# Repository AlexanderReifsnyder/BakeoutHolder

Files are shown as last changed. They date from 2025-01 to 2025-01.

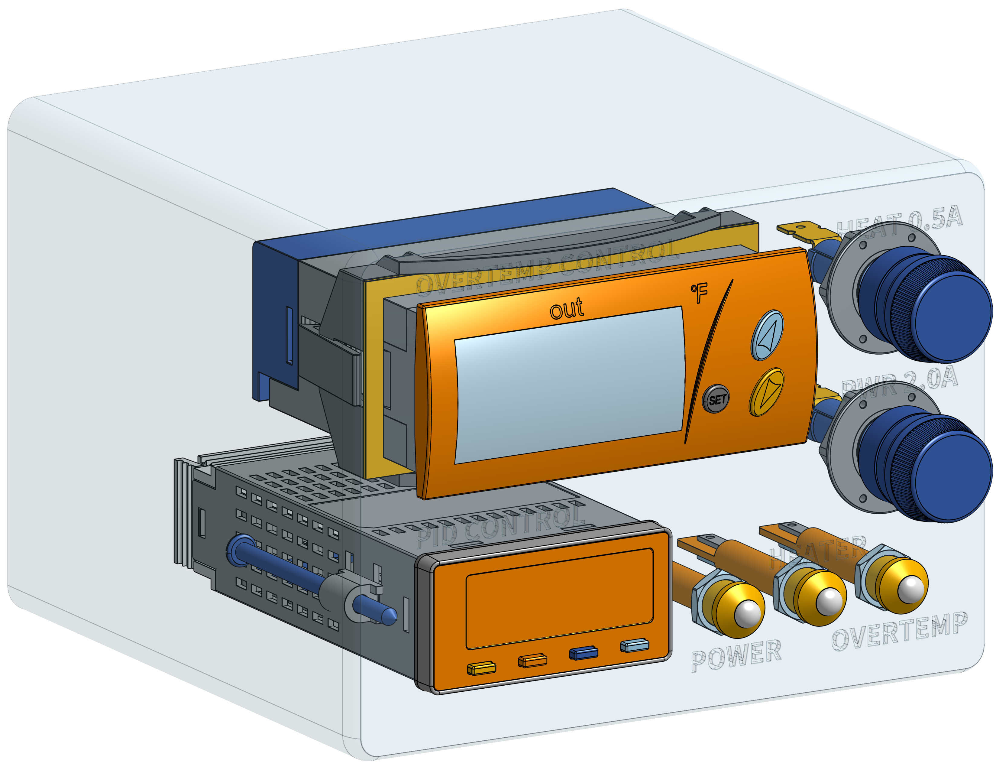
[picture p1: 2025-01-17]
Prototype/Version 1/Electronics/Controller Assembly Transparent V1.png

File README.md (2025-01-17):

# BakeoutHolder
The goal of this project was to create a heated holder for baking samples in a dry pumping station. The design is currenty in the prototype stage and should not be considered an official release. You may encounter incomplete features or unexpected behaviors - proceed at your own discretion. Th repository currently has STEP files for all physical components broken into folders depending on manufacturing method, and a BOM with links to the products used in our prototype.
This project has been released under the [Creative Commons Attribution-NonCommercial-ShareAlike 4.0 International license](https://creativecommons.org/licenses/by-nc-sa/4.0/?ref=chooser-v1).

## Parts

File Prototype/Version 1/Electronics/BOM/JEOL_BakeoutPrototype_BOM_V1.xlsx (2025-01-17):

Description | Qty | Units | Part Number | Supplier | Price/Unit | Subtotal
Insertion Heater with Standard Wire Lead Covering for 3/16" Hole, 120V AC, 1-1/2" Long Heating Element, 20W | 1 | Each | 3618K511 | McMaster Carr | $38.71 | $38.71
Thermocouple Probe for Air and Surfaces Type T, Wire Leads, 3 Feet Cable Length | 2 | Each | 9251T71 | McMaster Carr | $23.54 | $47.08
Electrical-Insulating Tube Sleeving with Acrylic Coating, 1/2" ID, 3 Feet Long | 1 | Each | 8268K72 | McMaster Carr | $11.66 | $11.66
Power Cord Light Duty, NEMA 5-15 Plug, 6 Feet Long, 0.31" Wide, SPT-1 | 1 | Each | 70355K85 | McMaster Carr | $4.14 | $4.14
Autotuning Temperature Controller with 1 Mechanical Relay Output, 1/32 DIN | 1 | Each | 38615K171 | McMaster Carr | $169.90 | $169.90
Super-Resilient Kalrez 7075 O-Ring Ultra-Chemical-Resistant, 1/16 Fractional Width, Dash 015 | 1 | Each | 1280N24 | McMaster Carr | $69.92 | $69.92
Panel-Mount Holder for Glass and Ceramic Tube Fuse for 1/10-16A Fuse, 0.25" Wide Straight Quick-Disconnect Terminal | 3 | Each | 7087K43 | McMaster Carr | $8.62 | $25.86
Glass-Tube Fuses Fast-Acting, Manufacturer Equiv: 217, GDB and Gsb, 2A | 1 | Pack of 5 each | 6978K769 | McMaster Carr | $6.71 | $6.71
Glass-Tube Fuses Fast-Acting, Manufacturer Equiv: 217, GDB and Gsb, 1/2A | 1 | Pack of 5 each | 6978K765 | McMaster Carr | $6.71 | $6.71
300V AC/300V DC Terminal Block Four 20A Circuits, 3/8" Center-to-Center | 3 | Each | 7527K44 | McMaster Carr | $3.35 | $10.05
Quick-Disconnect Terminals with Wire Lead, Female, for 14 Wire Gauge, Black, 12" Long | 1 | Pack of 10 each | 7548K34 | McMaster Carr | $25.11 | $25.11
12" Black Wire Lead for Panel Light | 3 | Each | 2779K802 | McMaster Carr | $2.76 | $8.28
12" Red Wire Lead for Panel Light | 3 | Each | 2779K801 | McMaster Carr | $2.76 | $8.28
Panel Light Quick-Disconnect LED, for 5/16" Panel Cutout Diameter, 120V AC, Green | 2 | Each | 2779K91 | McMaster Carr | $9.22 | $18.44
Panel Light Quick-Disconnect LED, for 5/16" Panel Cutout Diameter, 120V AC, Red | 1 | Each | 2779K91 | McMaster Carr | $9.22 | $9.22
Stranded Wire 300VAC, 20 Gauge, Blue/White Outer Insulation, 25 Feet Long | 1 | Each | 8054T14 | McMaster Carr | $4.44 | $4.44
Spade Terminals Vinyl Insulated, Standard, for 16-14 Gauge and Number 6 Screw | 1 | Pack of 50 each | 69145K214 | McMaster Carr | $16.08 | $16.08
Non-Bonding Heat Transfer Compound for 3D Printers, 0.2 FL. oz. Syringe | 1 | Each | 3715N11 | McMaster Carr | $12.19 | $12.19
Thermocouple temperature switch, type J/K/S Input, 110 V, °C. | 1 | Each | TCS-4011 | Dwyer Instruments | $103.75 | $103.75
Total |  |  |  |  |  | $596.53

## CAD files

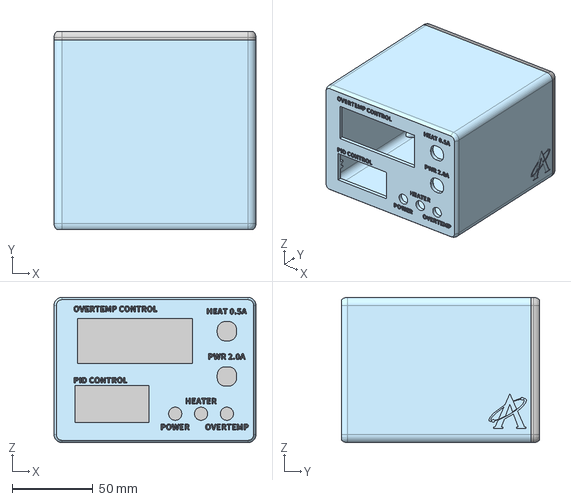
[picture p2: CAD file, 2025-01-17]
Prototype/Version 1/STEP Files/3D Printing/JEOL_BakeoutPrototype_Controller_CompleteV1.step
125.0 x 122.3 x 90.0 mm

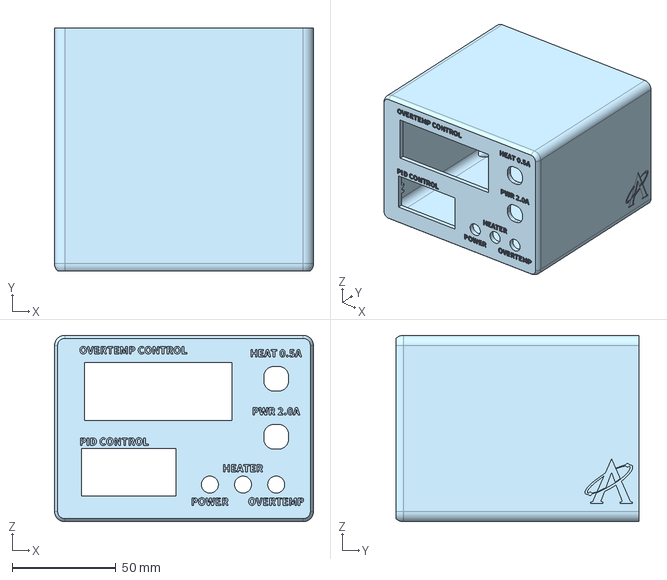
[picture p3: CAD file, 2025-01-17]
Prototype/Version 1/STEP Files/3D Printing/JEOL_BakeoutPrototype_Controller_MainV1.step
125.0 x 117.3 x 90.0 mm

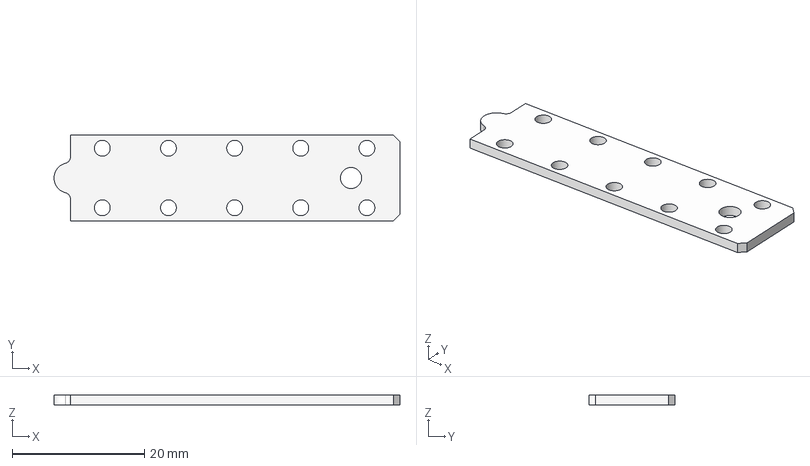
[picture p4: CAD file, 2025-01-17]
Prototype/Version 1/STEP Files/CNC Machining/JEOL_BakeoutPrototype_LidV1.step
52.3 x 13.0 x 1.50 mm

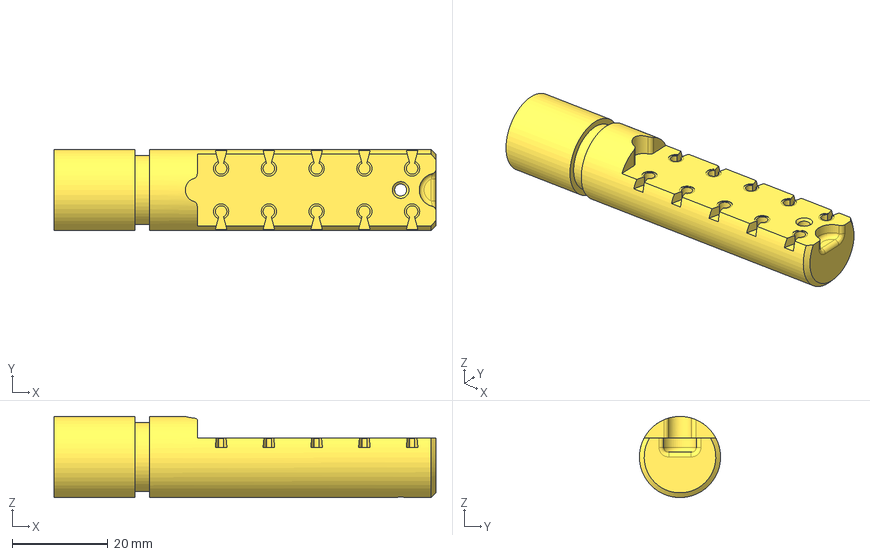
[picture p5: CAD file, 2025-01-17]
Prototype/Version 1/STEP Files/CNC Machining/JEOL_BakeoutPrototype_TipV1_1.step
80.0 x 17.0 x 17.0 mm

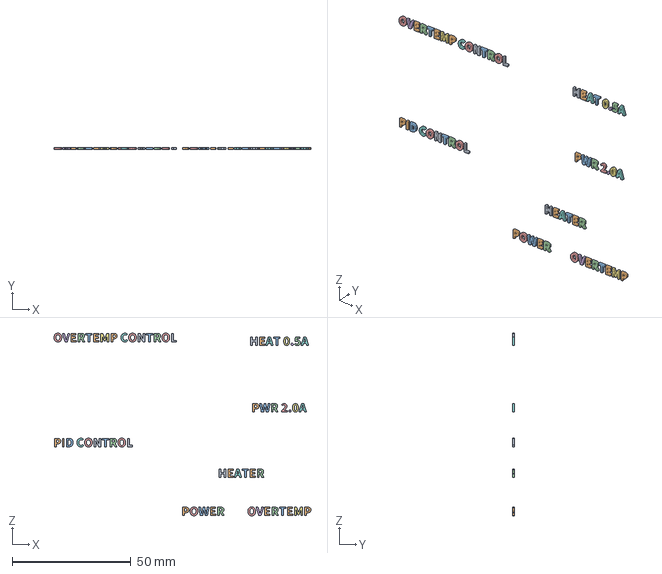
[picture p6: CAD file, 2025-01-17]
Prototype/Version 1/STEP Files/3D Printing/JEOL_BakeoutPrototype_Controller_TextV1.step
108.0 x 1.00 x 76.8 mm

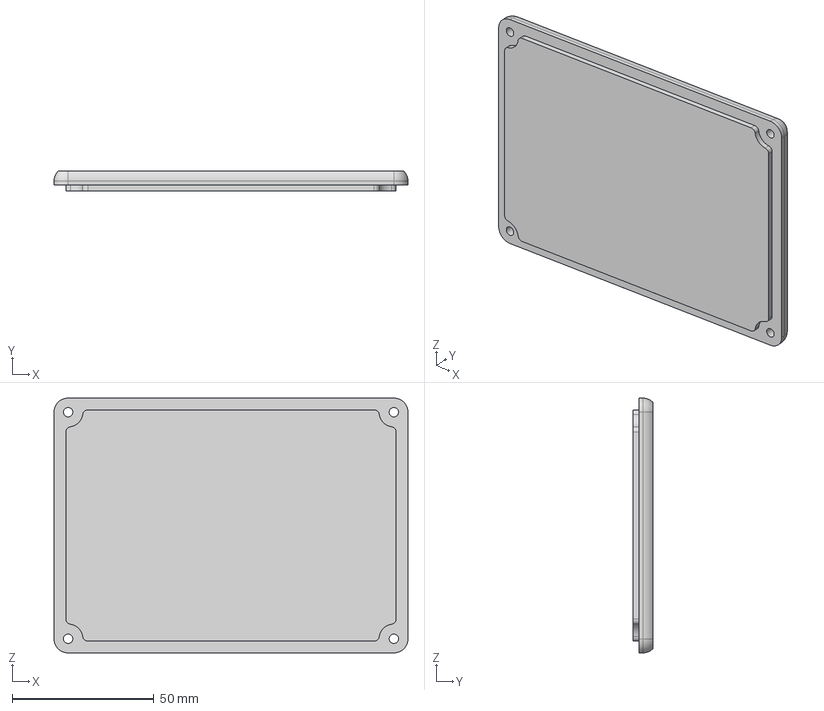
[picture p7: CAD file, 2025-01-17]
Prototype/Version 1/STEP Files/3D Printing/JEOL_BakeoutPrototype_Controller_BackNoCutoutsV1.step
125.0 x 7.00 x 90.0 mm

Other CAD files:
Prototype/Version 1/STEP Files/3D Printing/JEOL_BakeoutPrototype_Controller_BackNoCutoutsV1.stl
Prototype/Version 1/STEP Files/3D Printing/JEOL_BakeoutPrototype_Controller_MainV1.stl
Prototype/Version 1/STEP Files/3D Printing/JEOL_BakeoutPrototype_Controller_TextV1.stl

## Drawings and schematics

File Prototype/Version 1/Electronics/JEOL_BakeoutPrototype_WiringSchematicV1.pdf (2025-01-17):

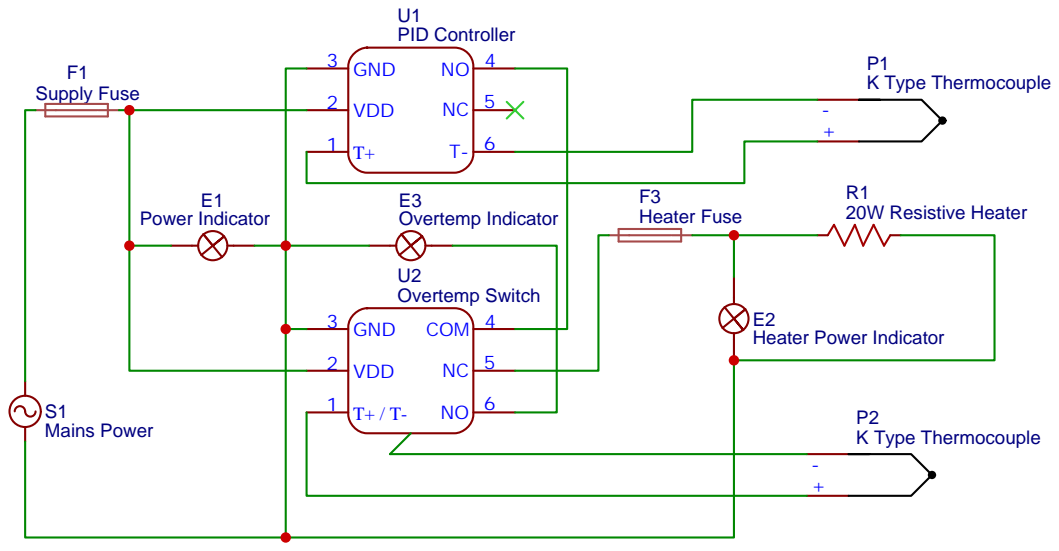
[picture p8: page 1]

Drawn By: Alexander Reisfnyder

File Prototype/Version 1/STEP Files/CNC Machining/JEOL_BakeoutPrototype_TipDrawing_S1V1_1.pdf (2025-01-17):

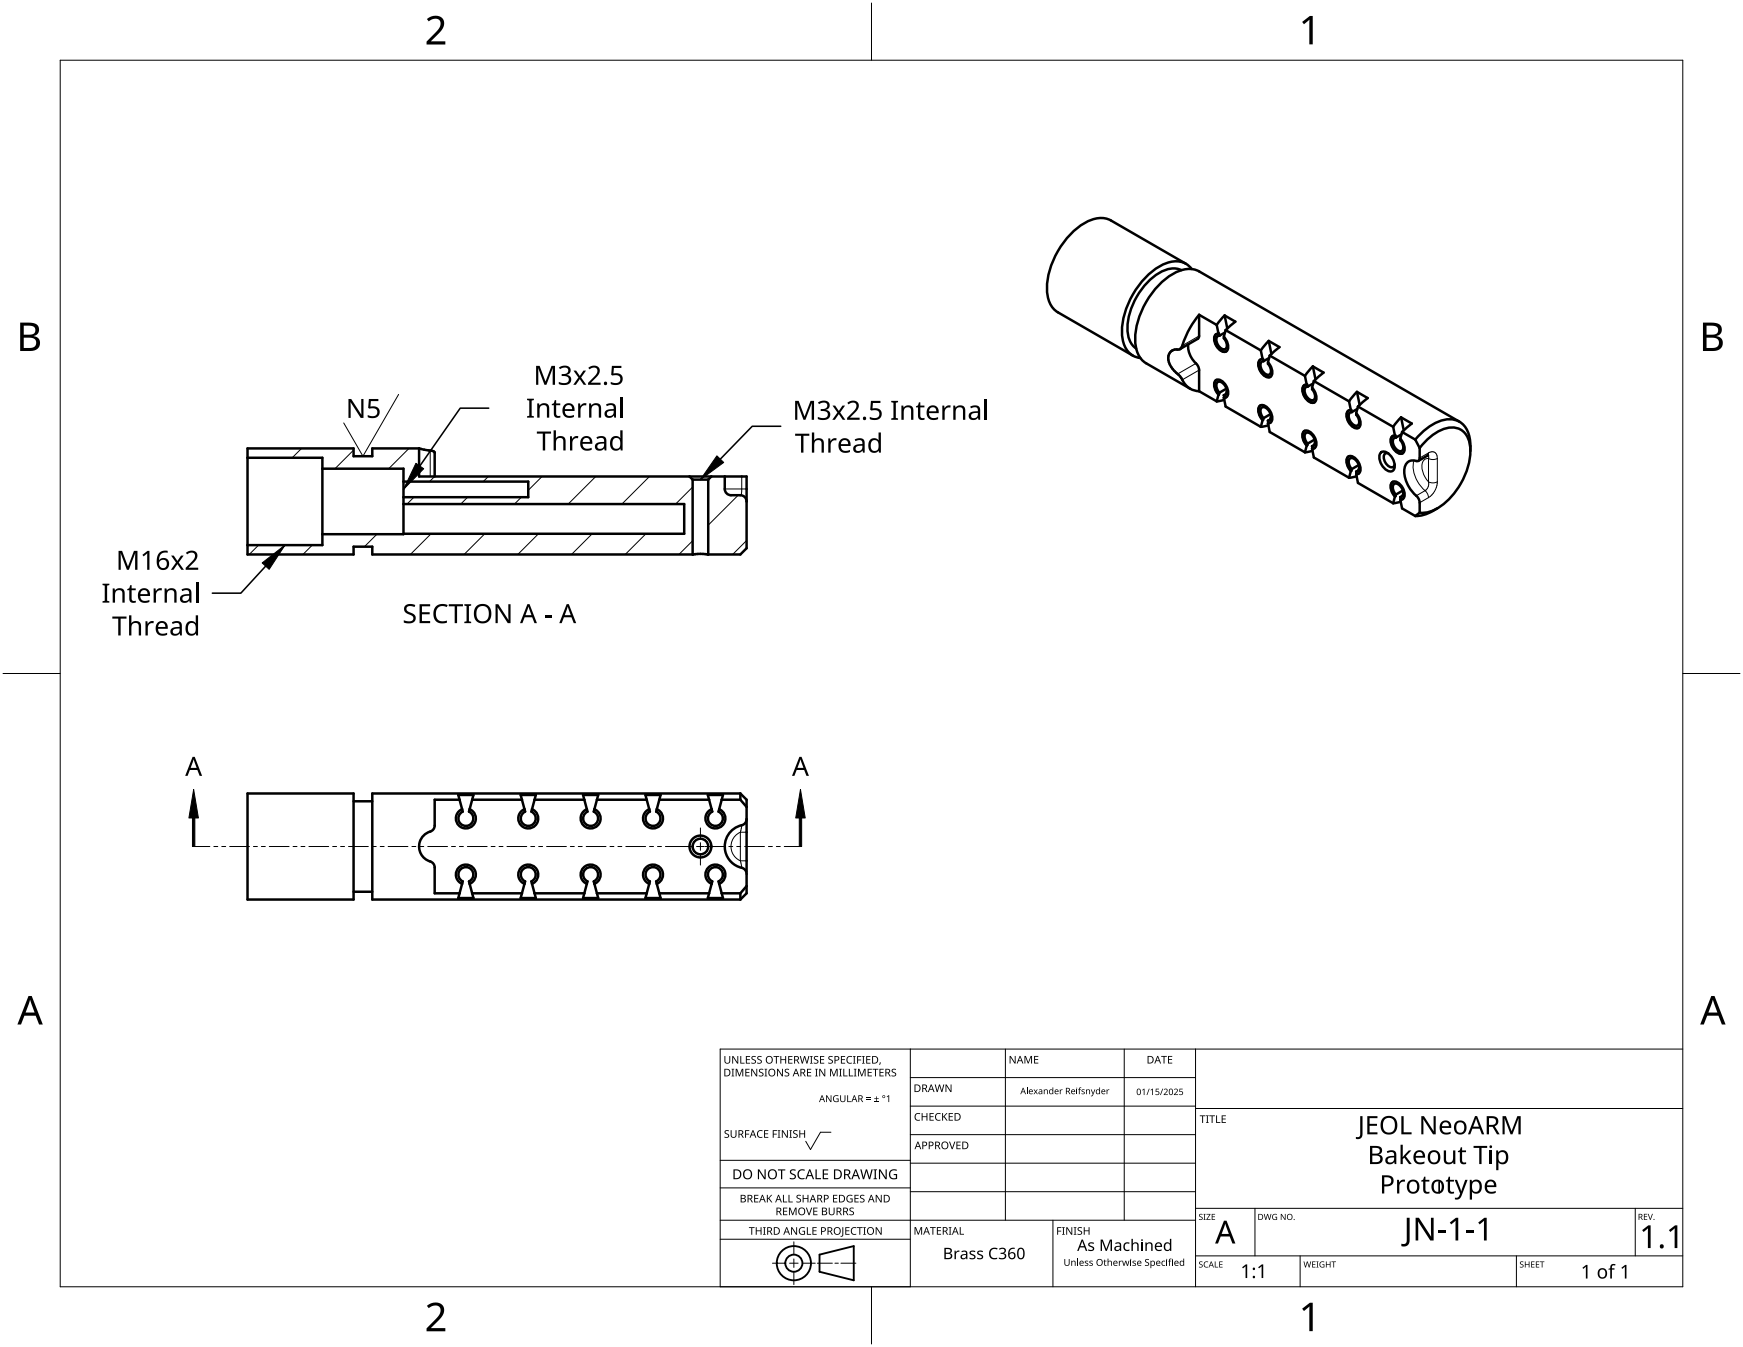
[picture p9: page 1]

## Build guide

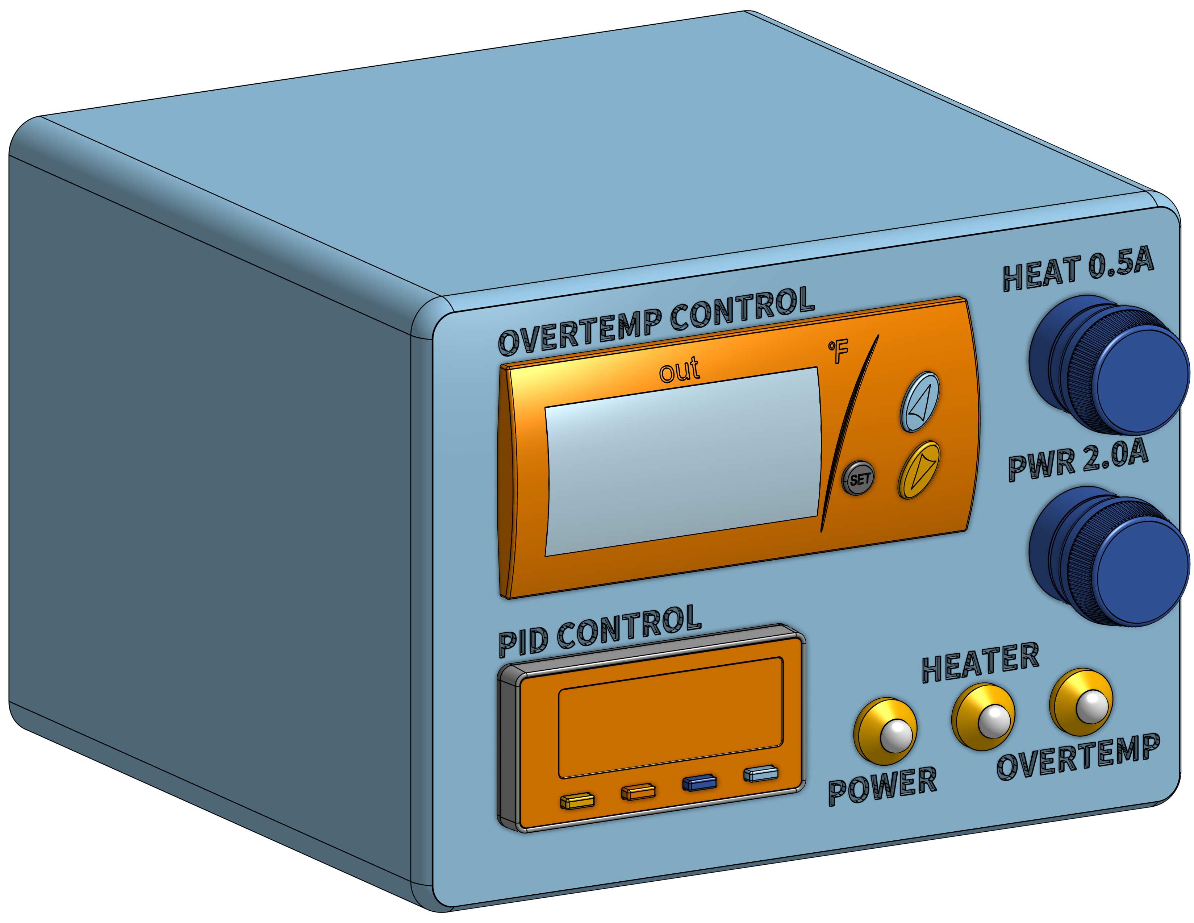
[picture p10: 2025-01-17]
Prototype/Version 1/Electronics/Controller Assembly Rendering V1.png
